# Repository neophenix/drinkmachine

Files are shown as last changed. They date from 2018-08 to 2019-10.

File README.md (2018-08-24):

# DrinkMachine

DrinkMachine is a raspberry pi powered bartender.  Using the provided [parts list](hardware/README.md) and wiring diagrams you can load this onto your pi and have it serving you drinks.

## Installation

Start with a lite [Raspbian](https://www.raspberrypi.org/downloads/raspbian/) install.  Then install a few packages to make life easier
```
sudo apt install git sqlite3
````

Next install golang, currently I use 1.10.3, to get that, and setup your paths, do:
```
wget https://storage.googleapis.com/golang/go1.10.3.linux-armv6l.tar.gz
sudo tar -C /usr/local -xzf go1.10.3.linux-armv6l.tar.gz
echo "export PATH=\$PATH:/usr/local/go/bin:~/go/bin" >> ~/.profile
echo "export GOPATH=\$HOME/go" >> ~/.profile
```

Now either `go get github.com/neophenix/drinkmachine` or otherwise copy this to your pi.

Setup the sqlite DB you'll need by using the .schema file in the db dir
```
sqlite3 drinkmachine.db < db/drinkmachine.schema
```
If you modified the wiring at all, you'll want to go into the DB and modify the pumps table, setting the correct GPIO pins for each pump.  See [db/README.md](db/README.md) for details on the db tables.

Last, build the binary and start the process
```
go build cmd/drinkmachine/drinkmachine.go
sudo ./drinkmachine
```
Note: sudo is required because the GPIO lib needs it and by default we want to use port 80

## Options

DrinkMachine has only a few command line flags to keep things simple
```
    -port       (default:80) which port to bind to
    -db         (default:drinkmachine.db) location of the sqlite3 DB
    -webroot    (default:web) location of the web dir (templates, static files, etc)
    -cache_templates (default:true) more for dev work, setting to false make the service read the web templates off disk each request
```

## Usage

Everything is done via the web interface (port 80 by default).  The main page lets you select a drink and pour it, then there are 3 "admin" pages

 * Manage Ingredients is the first place you should go, add all the alcohols, etc that you will want to use
 * Manage Pumps lets you select which ingredient is hooked up to each pump, it also lets you set the flow rate of the pump in ml/min.  The ones I used are rated for 100 ml/min and that is what the default is.
 * Manage Drinks is where you go to add all the cocktails you will want to make.  You give them a name, select an amount, units (the 3 common ones I know are defined, more can be added, PR welcome), and ingredient, and keep adding more ingredients as needed.  Then add some notes on finishing the drink or anything else you couldn't define elsewhere and save.

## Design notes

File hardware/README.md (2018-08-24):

# Parts and Diagrams

In this directory are two Fritzing diagrams and their exported PNG formats.  DrinkMachine.fzz and DrinkMachine.png are the current / supported diagrams.

Note on the _AllGPIO versions.  This was my initial go at buildin this using a GPIO LCD I had lying around.  This isn't supported in the code at all, but I've included it for historical sake, and maybe one day I'll add support for it.

The LCD is very lightly used today, to where you might ask "why is this here?".  I had plans to do more but as I wrote it all I just kind of forgot about the LCD.  I stil intend to go back and make more use of it, until then the answer to the question is "eh, why not?".

## Parts List

Everything I used, and I tried to include links to either where I got them or at least to show generally what it is.  You might be able to find deals elsewhere, when I bought a lot of this it was whatever was cheapest.  Note that this is still in flux, the original pump worked ok, but mounting was a pain, easier to mount pumps have been ordered but their amperage is quite a bit higher than the previous ones so the power supply needed swapped out.  Once a new version is entirely built and mounted I'll update this with the working parts.

```
Raspberry Pi Zero W (with headers) - https://www.raspberrypi.org/products/raspberry-pi-zero-w/
SainSmart 8ch relay - https://www.sainsmart.com/products/8-channel-5v-relay-module
SainSmart I2C LCD - https://www.sainsmart.com/products/16x2-iic-i2c-twi-serial-lcd-display-blue-on-white
8 x 12v Peristaltic pump - https://www.amazon.com/gp/product/B0791YL351
12v 5A power supply - https://www.amazon.com/gp/product/B073QTNF9F
12v -> 5v step down - https://www.amazon.com/gp/product/B00CXKBJI2

Misc Parts:
Food grade tubing for pumps, DO NOT use the cheap vinyl tubing they come with, and order the correct ID / OD for the pumps you use - https://www.amazon.com/gp/product/B0799FKWQ9
2.1 x 5.5mm female dc plug - https://www.amazon.com/gp/product/B00CUKHN0S
Micro USB connector - https://www.amazon.com/gp/product/B01KV4RANE
Butt connectors
Female crimp disconnect (pwr / gnd to pumps)
Heat shrink tubing
Various wiring, 22awg and I used some thermostat wiring for the pumps since it was cheap at your local home improvement store
ideal in-sure push-in wire connectors (seemed easiest to tie the pumps to the power) - http://www.idealindustries.ca/products/prodSelect.php?prodId=30-1034
Mounting hardware - https://www.amazon.com/gp/product/B01E8JZWZ6 https://www.amazon.com/gp/product/B01IYWTCWW
```

## Diagrams

Just a quick note on the diagrams.  I'm new to fritzing and a lot of this hardware work, so I tried to find exact parts as I could.  You'll notice some notes where I could not find the parts like the 12v power and the step-down.  If anyone knows where I can find a parts file for these that would be great!

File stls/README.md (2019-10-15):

# Drinkmachine STLs

In here are all the files you should need to print out a case for the drinkmachine, assuming you've used the same parts I have, or at least ones with the same dimensions.  The case is somewhat modular, so if you have different diameter tubes you could print out just those sections, same with pumps, plug, LCD, etc.

The LCD is worth noting that even if you have the same one I do, it was not square, hence the seemingly misaligned holes.  This was so the actual screen is straight when looking at it, so your mileage may vary.

The holes are a start of me exporting all the individual pieces that make up the case, so you can use them to build your own.  They were exported as solid objects so you can then import them and change them to a hole / negative space, whatever your design program calls it.

In misc, there is a test print that I used to make sure all the various connectors fit, and generally that my printer (ender-3) was calibrated correctly.

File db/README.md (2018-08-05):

# DB

Below describes all the tables and their cols

## pumps
Stores all the info about the connected pumps, this is created for you by running the provided schema file
 * pump_id (int) - integer id of the pump, I prefer to number them in the order that users will see them from left to right
 * flow_rate (real) - the amount of fluid the pump moves in ml / min
 * ingredient (text) - what is hooked up to this pump
 * gpio_pin (text) - the pin this pump (or relay) is connected to in the form 'GPIO_X'

## ingredients
All the various alcohols, or whatever else you want to hook up to this go here
 * ingredient (text) - the name of whatever it is that is hooked up
 * viscosity (real)- unused at this moment, this was meant to allow users to adjust the flow rate when pumping this liquid.  In theory how this will be used is if you pump something that only gets 80ml/min but the pump would do 100, you set this to .8 and then we mutliply the flow rate by it before pumping.  In some very minor tests I did it didn't seem to really change so I haven't used it at all, your mileage may vary.

## drinks
 * drink_id (int, pk) - numeric id of the drink, not exposed directly to users
 * name (text) - whatever you call this concoction
 * notes (text) - this is for when the machine is done making the drink, we will show the user notes of anything that needs done to finish the drink, garnish, whatever you want.  Don't add extra ingredients here (well you can if you want) but you can do that via normal drink ingredients by unchecking the dispense checkbox

## drink_ingredients
 * ingredient (text) - which ingredient we are adding
 * amount (real) - how much of the ingredient
 * units (text) - what the amount represents, ml, cl, oz, dash
 * dispense (bool) - are we going to pump this or not, an example of something that we would not dispense are bitters
 * drink_id (int, fk -> drinks) - links this to a drink

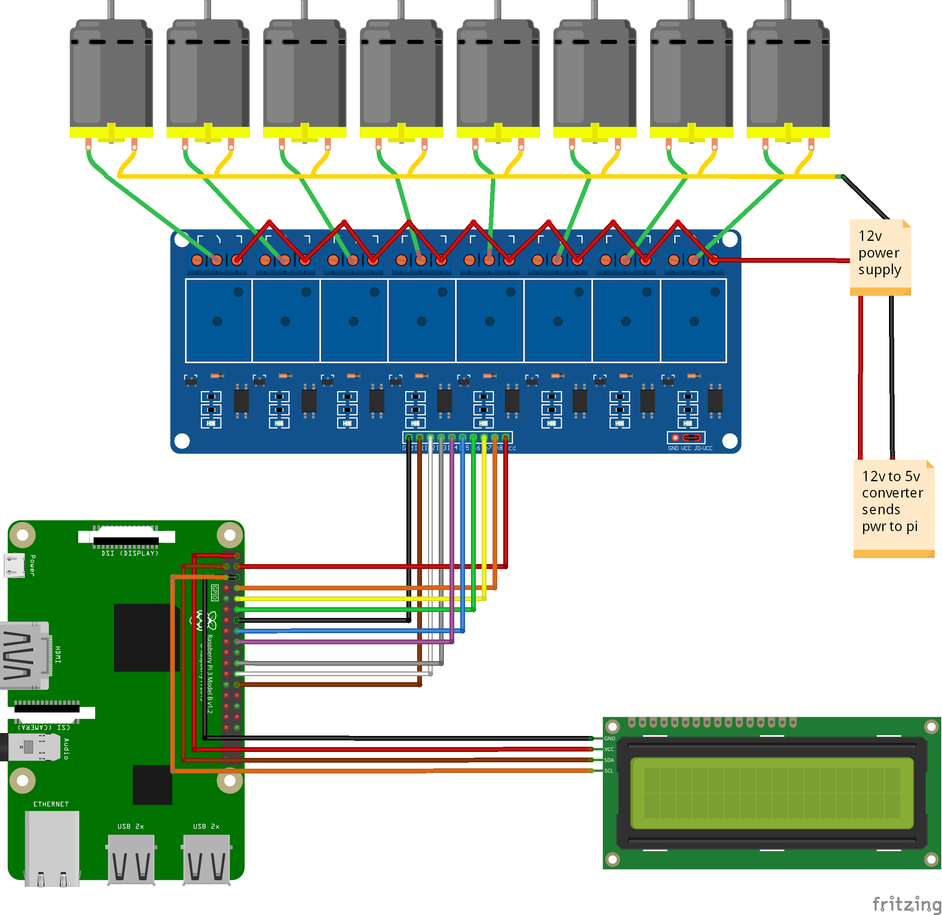
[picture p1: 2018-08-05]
hardware/DrinkMachine.png

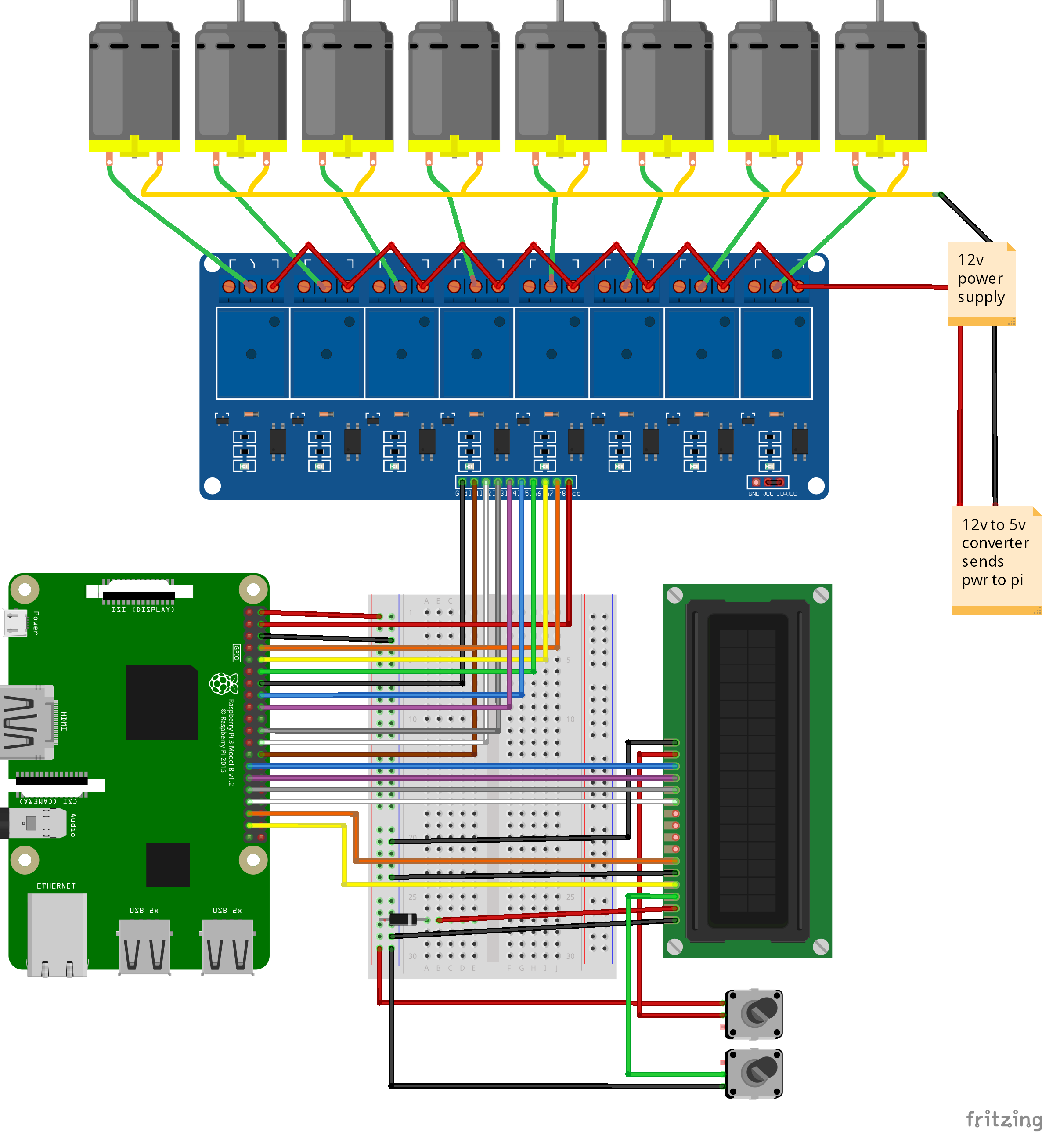
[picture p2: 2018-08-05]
hardware/DrinkMachine_AllGPIO.png

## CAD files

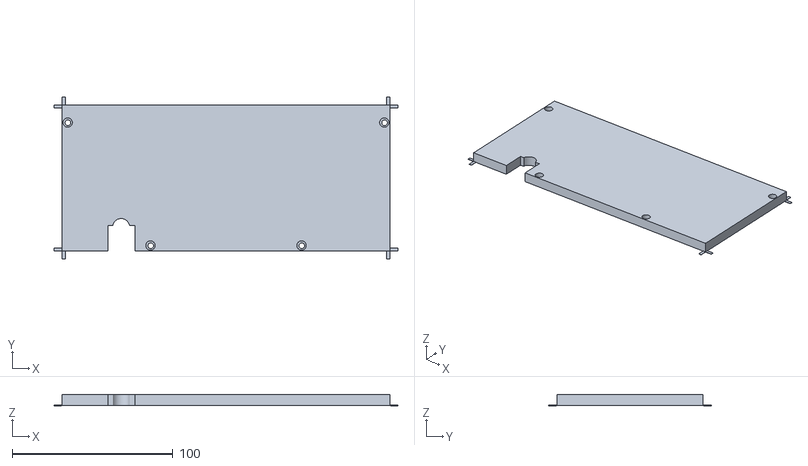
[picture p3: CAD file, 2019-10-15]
stls/Back/Drinkmachine Back.stl
214.0 x 101.0 x 7.00

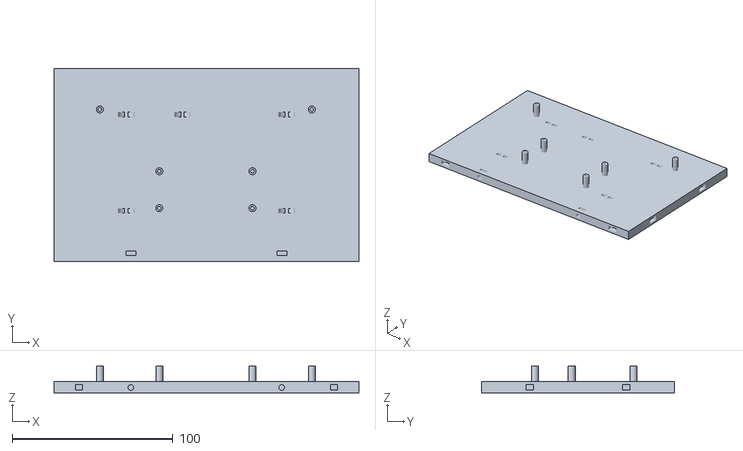
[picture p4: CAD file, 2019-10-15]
stls/Bottom/Drinkmachine Bottom - Front.stl
190.0 x 120.0 x 16.7

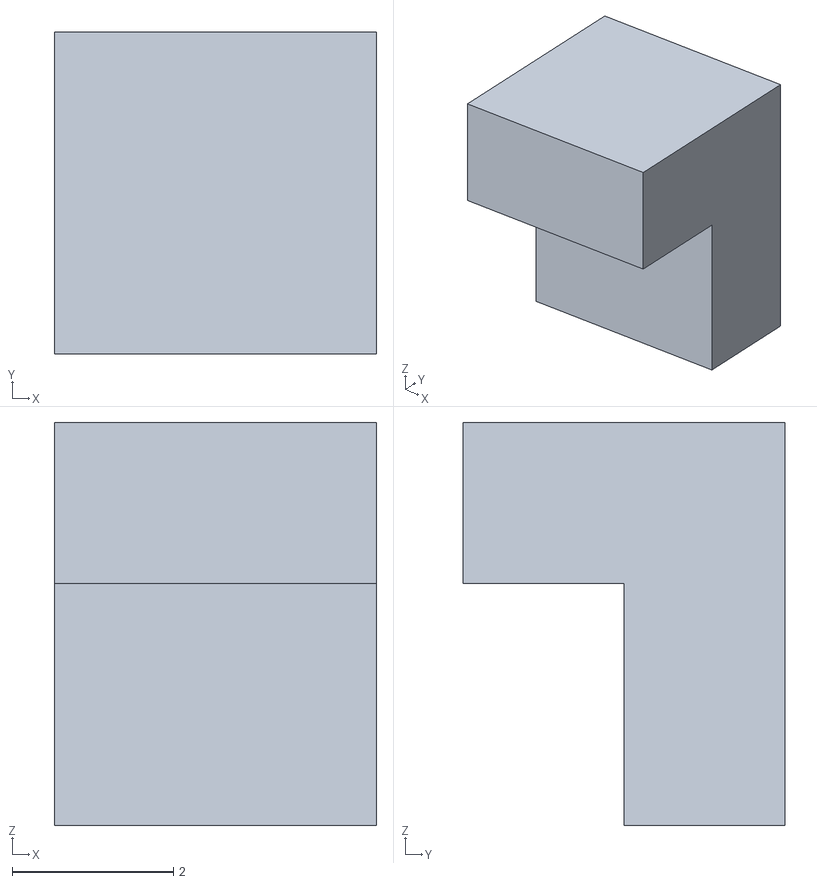
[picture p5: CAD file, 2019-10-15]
stls/Connectors/Nozzle Mount.stl
4.00 x 4.00 x 5.00

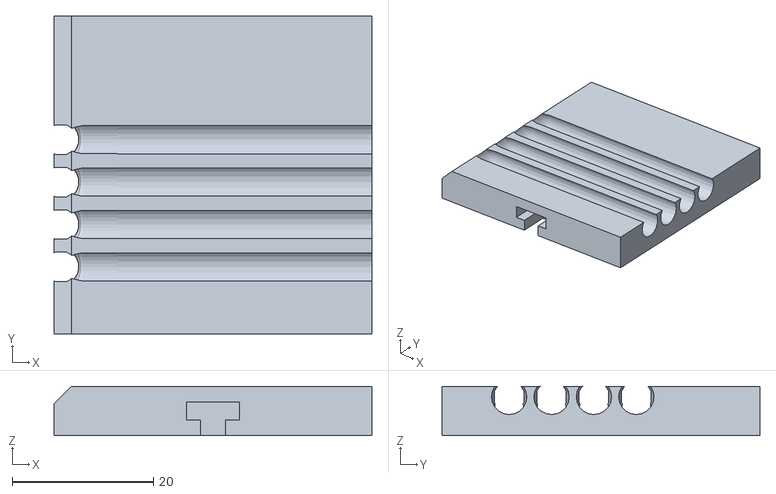
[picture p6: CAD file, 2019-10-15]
stls/Front/Drinkmachine Front - Lower Left.stl
45.0 x 45.0 x 7.00

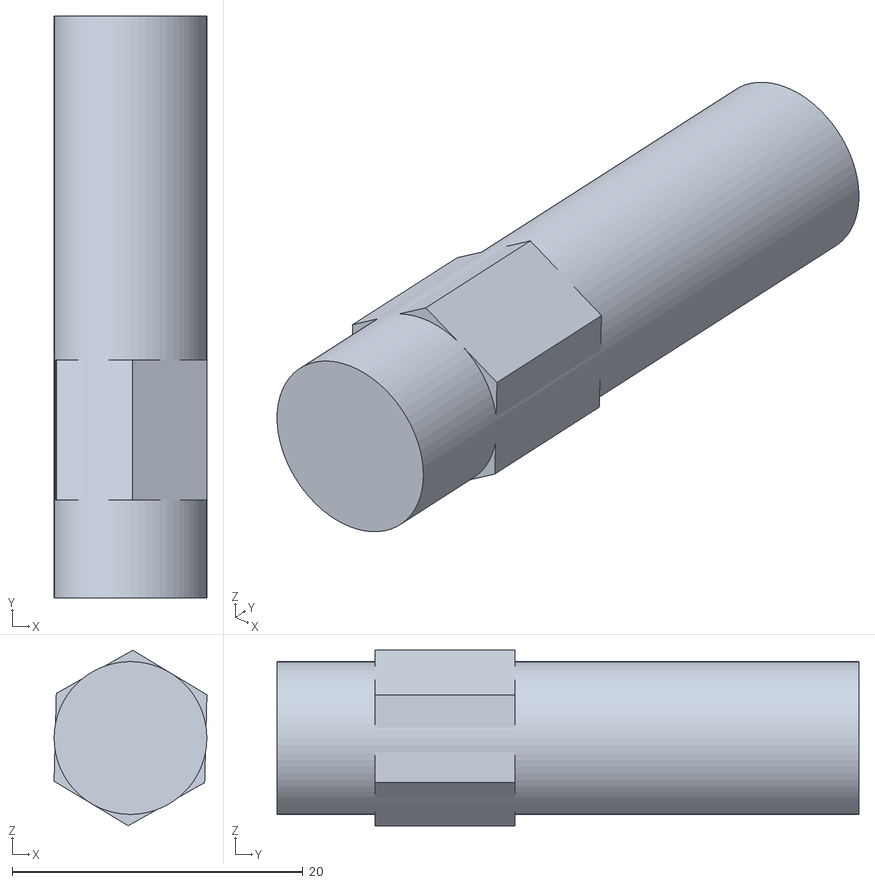
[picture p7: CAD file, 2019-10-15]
stls/Holes/Plug Mount Holder.stl
10.5 x 40.0 x 12.1

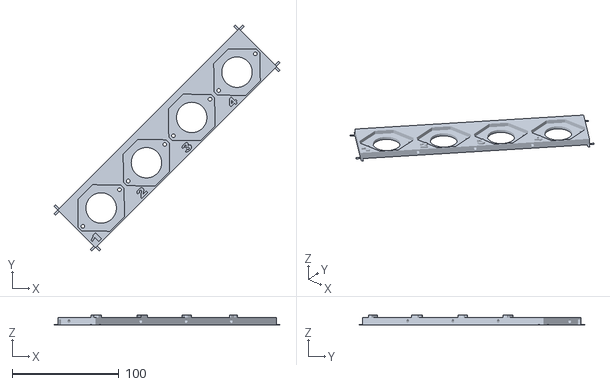
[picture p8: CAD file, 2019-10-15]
stls/Left Side/Drinkmachine Side - Left Top.stl
211.8 x 211.8 x 9.00

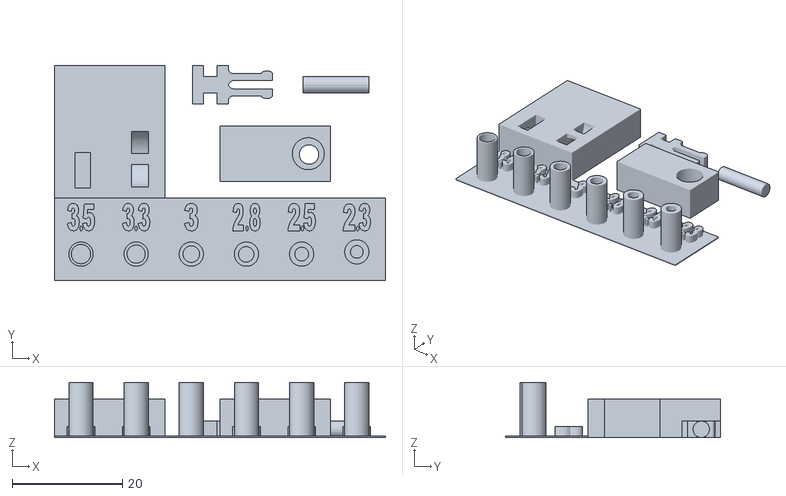
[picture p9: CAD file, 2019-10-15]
stls/Misc/Test Pieces.stl
60.0 x 39.0 x 10.00

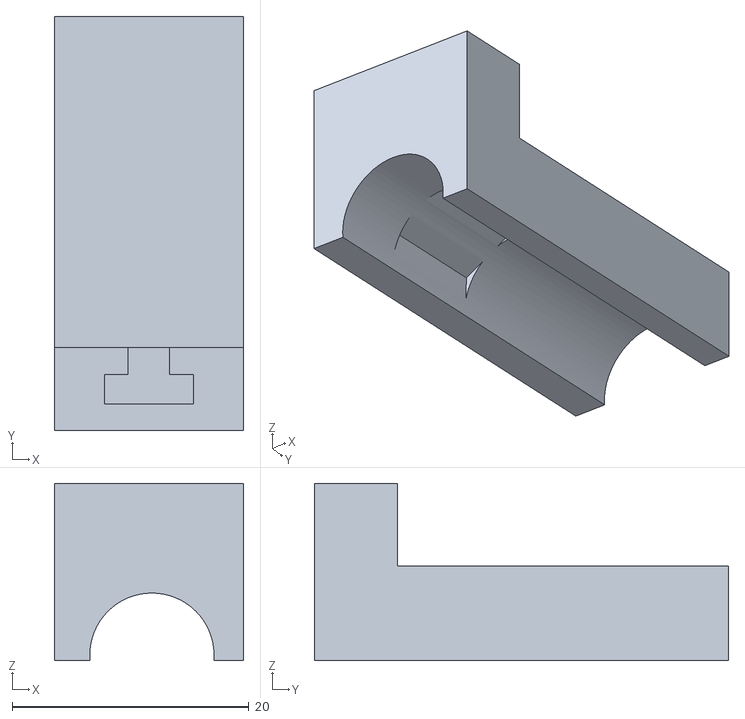
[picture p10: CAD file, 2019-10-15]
stls/Back/Drinkmachine Back - Plug Mount.stl
16.0 x 35.0 x 15.0

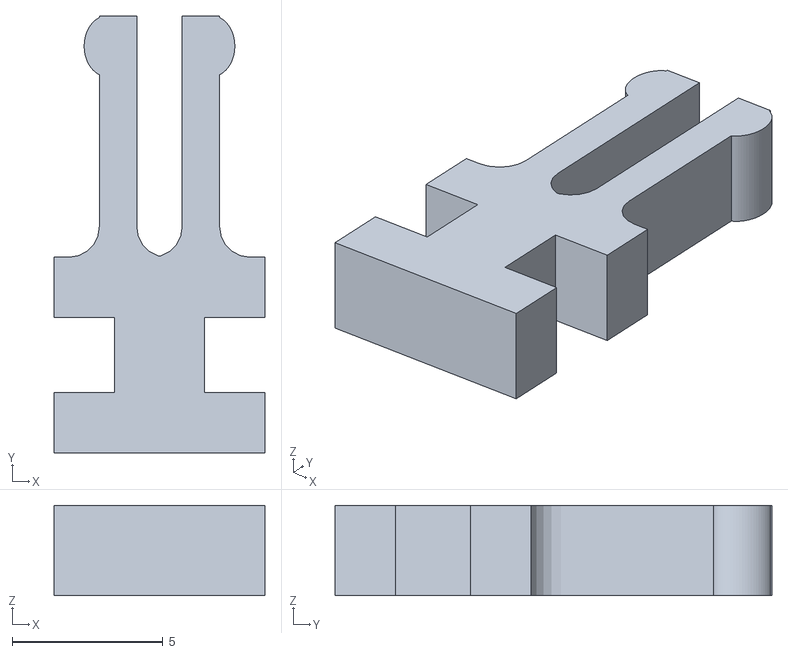
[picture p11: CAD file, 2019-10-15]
stls/Connectors/Bottom to Side Clip.stl
7.00 x 14.5 x 3.00

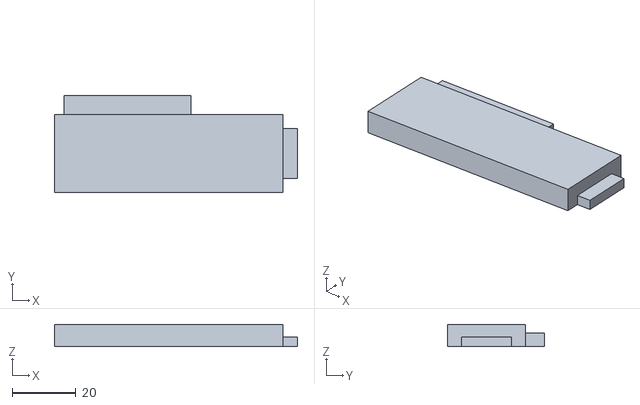
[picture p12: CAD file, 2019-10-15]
stls/Holes/LCD.stl
76.5 x 30.5 x 7.00

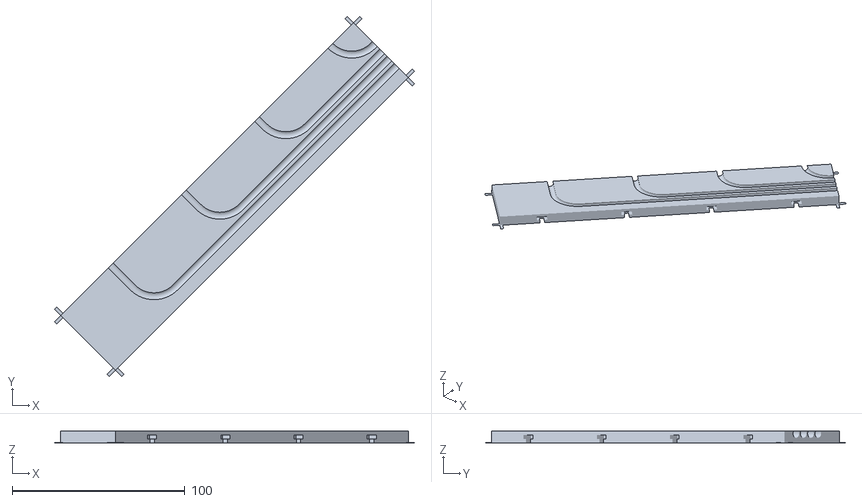
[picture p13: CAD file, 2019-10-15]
stls/Left Side/Drinkmachine Side - Left Bottom.stl
208.6 x 208.6 x 7.00

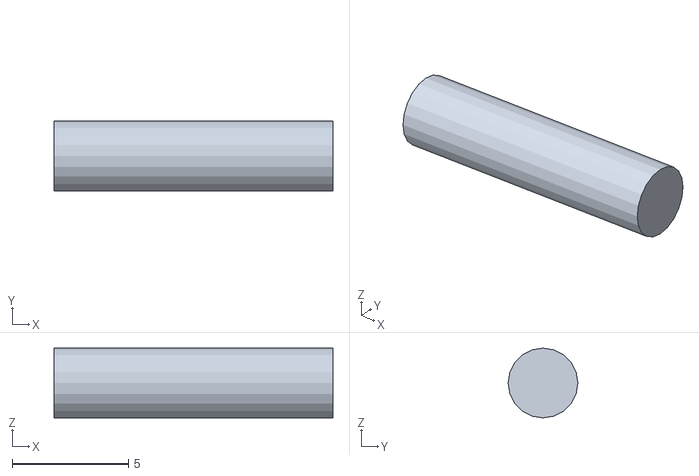
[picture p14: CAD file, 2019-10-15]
stls/Connectors/Cylinder.stl
12.0 x 3.00 x 3.00

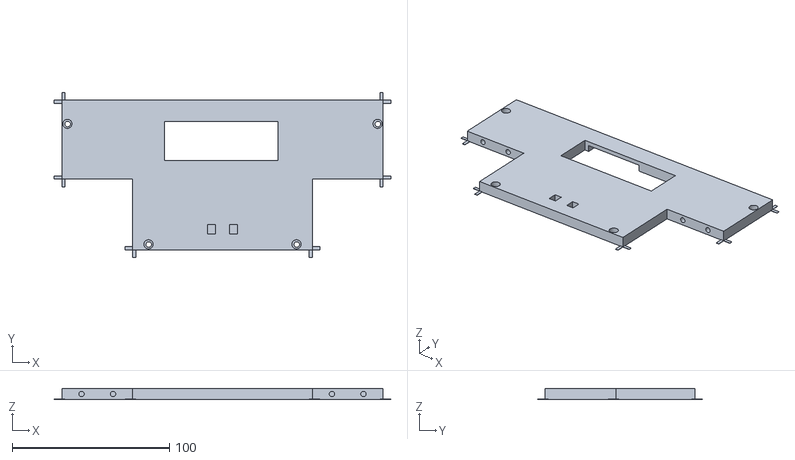
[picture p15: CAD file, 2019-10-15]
stls/Front/Drinkmachine Front.stl
214.0 x 105.0 x 7.00

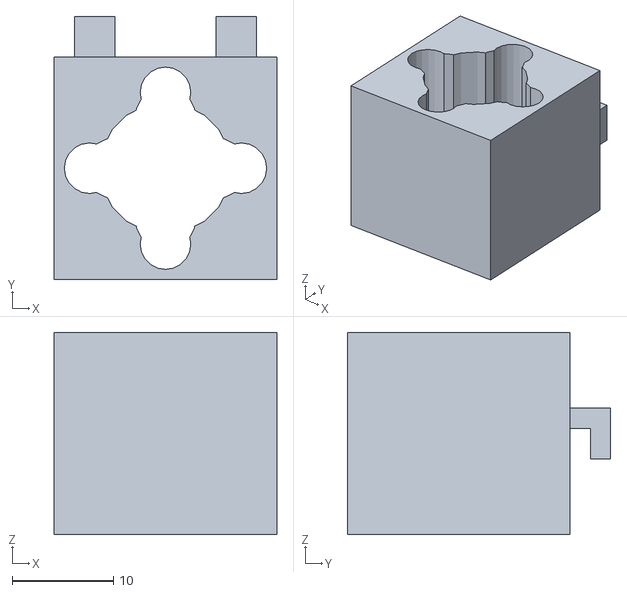
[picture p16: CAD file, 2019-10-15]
stls/Front/Drinkmachine Front - Nozzle.stl
22.0 x 26.0 x 20.0

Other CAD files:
stls/Right Side/Drinkmachine Side - Right Top.stl
stls/Bottom/Drinkmachine Bottom - Rear.stl
stls/Front/Drinkmachine Front - Lower Right.stl
stls/Right Side/Drinkmachine Side - Right Bottom.stl
stls/Holes/Bolt Only.stl
stls/Holes/Bottom Clip.stl
stls/Holes/Cylinder.stl
stls/Holes/LCD Screw.stl
stls/Holes/Nozzle Mount.stl
stls/Holes/Nozzle.stl
stls/Holes/Nut and Bolt.stl
stls/Holes/Plug Mount Rear Opening.stl
stls/Holes/Pump Mount Bolt Hole.stl
stls/Holes/Pump Mount Hole.stl
stls/Holes/Pump Mount Plate.stl
stls/Holes/Side T Mount.stl
stls/Holes/Tube Channel Curve 1.stl
stls/Holes/Tube Channel Curve 2.stl
stls/Holes/Tube Channel Curve 3.stl
stls/Holes/Tube Channel Curve 4.stl
stls/Holes/Tube Channel Front Trim.stl
stls/Holes/Tube Channel Front.stl
stls/Holes/Tube Channel Straight.stl
stls/Holes/Zip Tie.stl

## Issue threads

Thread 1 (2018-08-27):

Add stop button

neophenix, 2018-08-27:
Useful if it is pouring and one of the ingredients runs out, you should be able to stop it and then fill in the missing on your own.  Added points if it lists the amounts you need to add then.

neophenix, 2018-09-09:
Done, doesn't list out what it didn't pour, will revisit that later if I decide its useful (needs more trial runs)

Closed 2018-09-09.

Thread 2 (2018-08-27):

Add priming or "run pump for X seconds" buttons

neophenix, 2018-08-27:
Priming now is only really done by making a "priming drink" and setting the only ingredient to the new thing you added with some low amount.  It would be easier if on the pump page there was a "run for x seconds" button.

neophenix, 2018-09-08:
Done

Closed 2018-09-08.

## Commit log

2018-08-05 DrinkMachine initial commit
    [DrinkMachine.fzz, DrinkMachine_AllGPIO.fzz]
2018-08-09 remove comment about pumps being left -> right since the physical layout is up to to whomever is building it
2018-09-08 Add ability to run a pump for some amount of time
    * Moved locking to the hw package / pump file since more
    than one thing will use it, and we really only lock if
    a pump is in use
    * Add websocket command to run a pump for some number of seconds
    * Add HTML / JS to support running a pump
    * Fixed up and error reporting that wasn't being handled before
2018-09-09 Add Stop Pouring button when making a drink
    * Main makeDrink loop now sleeps for 1 second instead of
    for however long it would be until the next pump is done
    * Each loop we check for timeRemaining and the stopRunning flag
    * If we cut the drink short, return to the UI like we finished
    until there is more logic in the backend to do something else
    * Stop button just sets the stopRunning flag = true, with the
    new sleep the pumps should stop within a second. If its hit
    during the initial timeout the drink never pours
2018-09-09 Allow making a drink with missing ingredients
    * Show a warning with an "override" button
    * List out what we didn't pour when done like any finishing items
    fixes #3
2019-10-15 STL files for a Drinkmachine case (#7)
    Many many hours of design and work, mostly learning how to do
    this and how to use Tinkercad. If you use the same hardware
    as me you might be able to print everything as is, but I would
    highly recommend test prints and fit tests.
    [Bolt Only.stl, Bottom Clip.stl, Bottom to Side Clip.stl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]
